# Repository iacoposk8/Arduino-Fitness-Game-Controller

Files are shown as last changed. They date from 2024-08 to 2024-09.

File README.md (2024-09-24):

Support me (https://buymeacoffee.com/iacoposk8)

# Arduino Fitness Game Controller
This project showcases an innovative Arduino-based controller that simulates the left analog stick of a gamepad, enabling control of in-game movements through physical activity. The controller is designed to be mounted on the user's back and integrates with exercise equipment like treadmills, stationary bikes, and ellipticals.

## Watch the demo video on YouTube
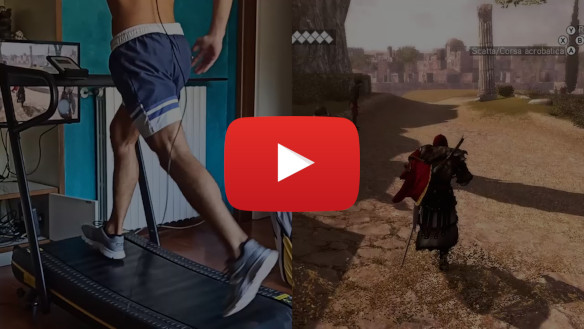
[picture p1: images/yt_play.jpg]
Demo video of the project (https://www.youtube.com/watch?v=4EYHZWyAiZI)


Demo gif of the project

## How to use

### Requirements

* Arduino nano
* GY-521 MPU-6050 accelerometer

### Electrical connections
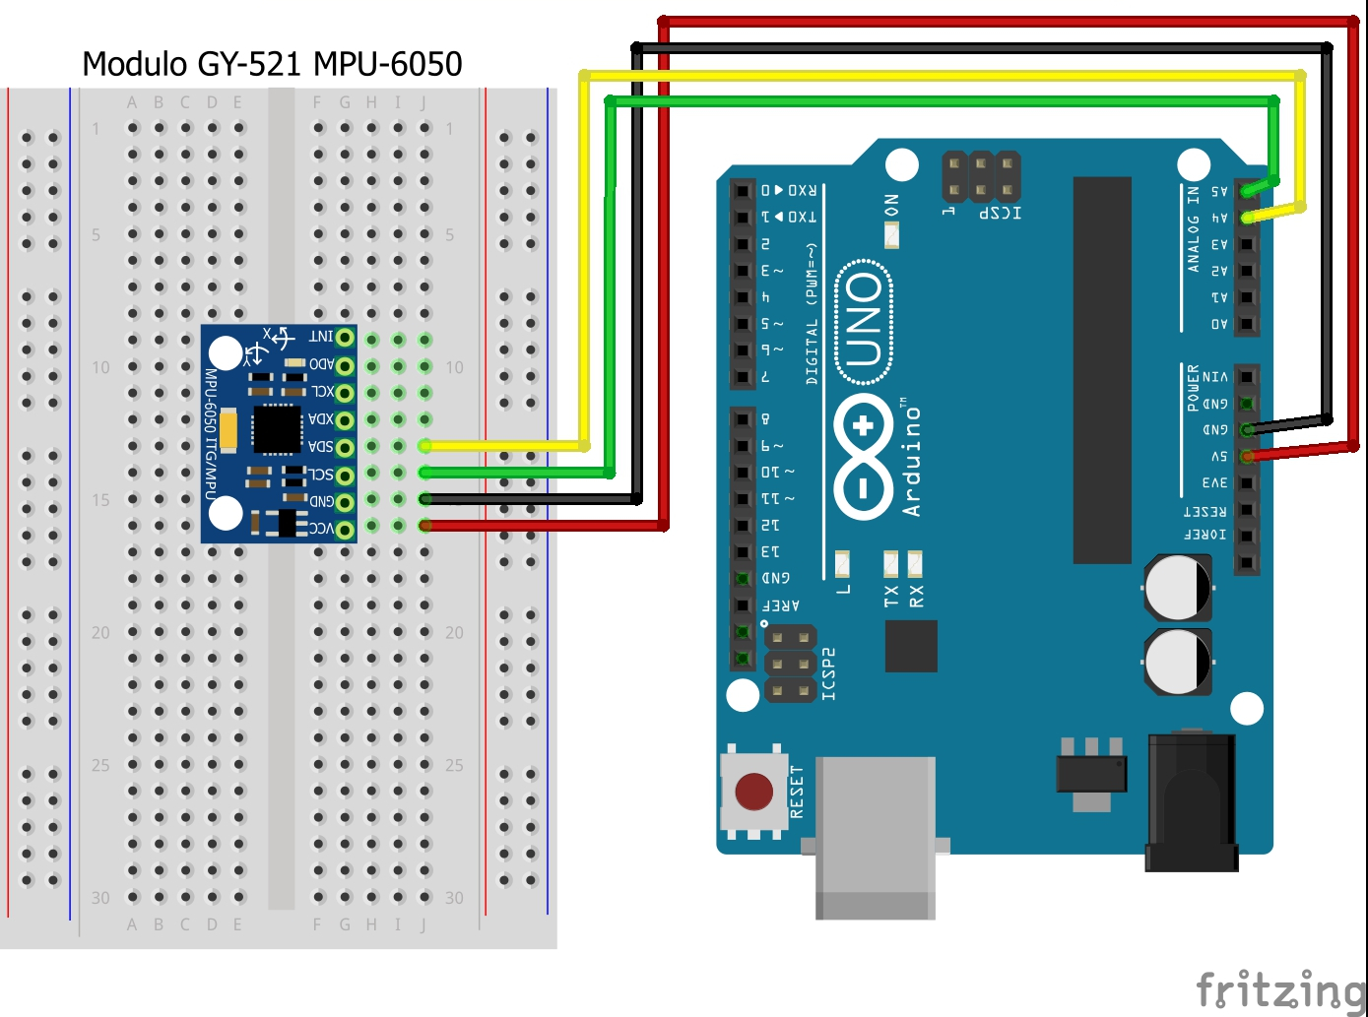
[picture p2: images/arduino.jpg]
Electrical connections


### Arduino code
Upload the code from the Accelerometer.ino file to your Arduino.
This code simply reads the accelerometer and sends the data to the serial port which will then be read by Controller.py

### Controller code
The Controller.py file will simulate the Xbox joystick and by reading the data from the arduino it will move the left analog stick.

I still need to create a requirements.txt file, but these commands probably install all the dependencies:
```
pip install pyserial
pip install numpy
pip install vgamepad
pip install matplotlib
```
### Configurations

In the first lines that follow `def __init__(self):` there are a few variables to configure to make the best use of the controller.

When we run we have vertical and horizontal oscillations that we could represent graphically as a sinusoid.
However, when we use a joystick, if we want to go in a direction, for example forward, we will not intermittently tap our analog stick, but we will tilt it forward while keeping it in that position.
So, if we took the raw data from the accelerometer while we are running, our character would continue to stop and start turning right and left at each of our steps.
So the code takes a sample of measurements and makes an average.
The larger the sample, the fewer errors there will be, but there will be a delay in executing the command.

The lower the value, the less movement of the shoulders to turn
```
self.x_range = 0.8
```

Threshold which, if exceeded, will start the curve
```
self.x_threshold = 0.4
```

The lower the value, the lower the speed at which we should run to make our character go at maximum speed
```
self.y_max_speed = 2.5
```

Speed with which we want, walk, run and run fast
Speed with which we want, walk, run and fast run
Currently the fast run is activated by pressing the "A" button on the Xbox controller. If you want to change it just change the lines:
gamepad.press_button(button=vg.XUSB_BUTTON.XUSB_GAMEPAD_A)
and
gamepad.release_button(button=vg.XUSB_BUTTON.XUSB_GAMEPAD_A)
With one of the commands that can be found here:
[https://pypi.org/project/vgamepad](https://pypi.org/project/vgamepad).

```
self.speed = {
	"walk": 0.06,
	"run": 0.3,
	"fast_run": 0.7
}
```

The higher the value, the less the left analog stick y-position flickers, but the return to zero position will be slower
```
self.n_sample_x = 2
self.n_sample_y = 10
```

If set to True the code will automatically find the right port, if it doesn't work, set it to False and during execution it will show you all the ports to choose from
```
automatic_choice_port = True
```

Optional ability to enable various types of debugging with graphs and logs
```
self.show_value = False
self.show_plot = False
self.x_plot = 200
self.debug = True
```
### 3D printing

In the Stl folder there are the files for 3d printing and the blender file for editing. This is the part of the project that needs to be fixed the most, in the future I will solder Arduino and the accelerometer so as not to have wires and I will be able to create a closed case. But for those who want to try this project these models are enough.
You will find two folders, one with the models with clips and one without clips.

| With clip | Without clip |
|--|--|
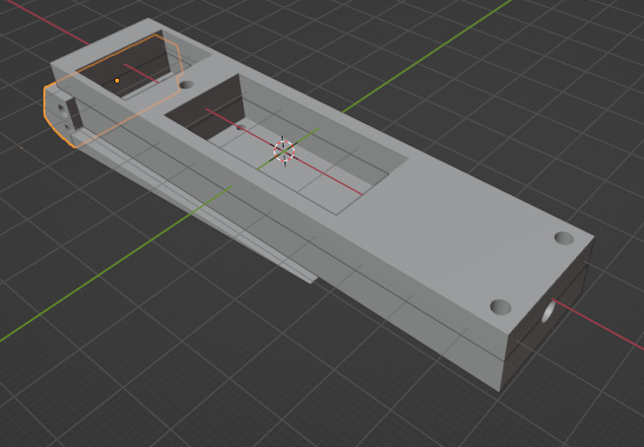
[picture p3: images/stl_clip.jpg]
Support with clip
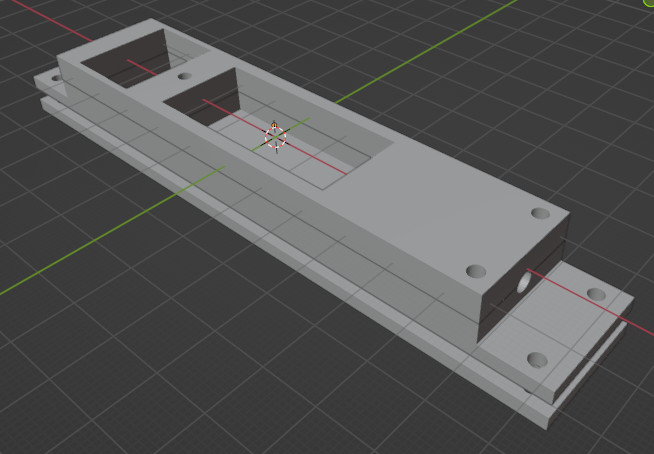
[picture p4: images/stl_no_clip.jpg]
Support without clip
|  |  |

The model without clips can be mounted on [this back support by Dreamfit](https://www.amazon.it/gp/product/B07QPVP33F).
The model with clips goes on all shirts but you will notice that it will swing a lot while running, so you will have to find a way to fix the cable at the bottom of the shirt or in the middle.

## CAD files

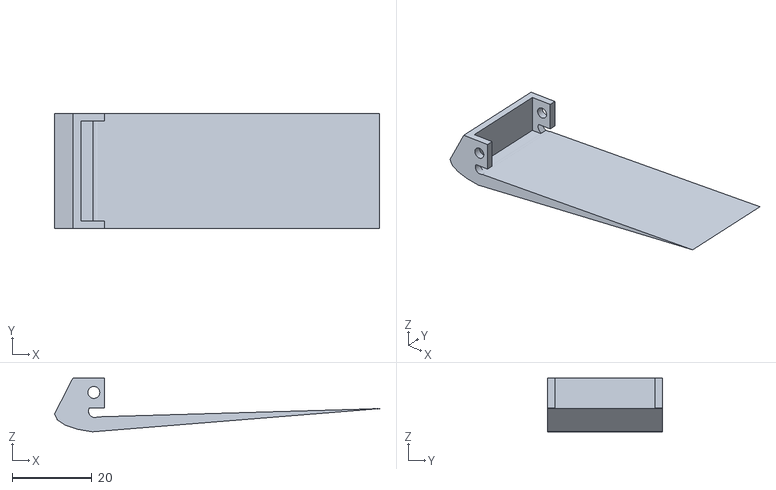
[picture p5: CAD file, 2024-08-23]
Stl/Clip/clip.stl
81.6 x 29.0 x 13.6

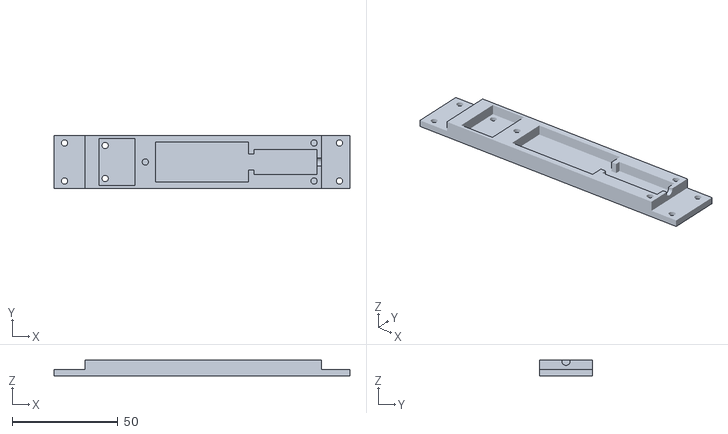
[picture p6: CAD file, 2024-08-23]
Stl/Without clip/bottom.stl
140.0 x 25.0 x 7.50

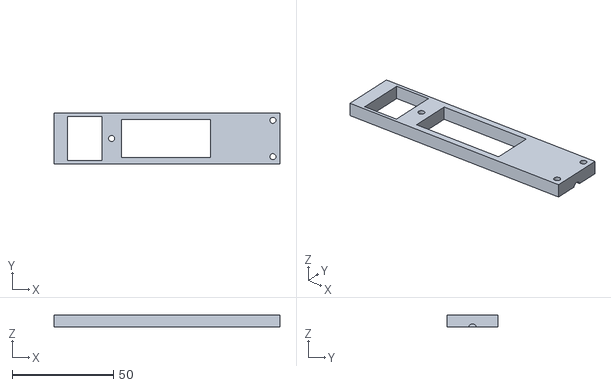
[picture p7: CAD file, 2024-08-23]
Stl/Clip/top.stl
111.8 x 25.0 x 6.00

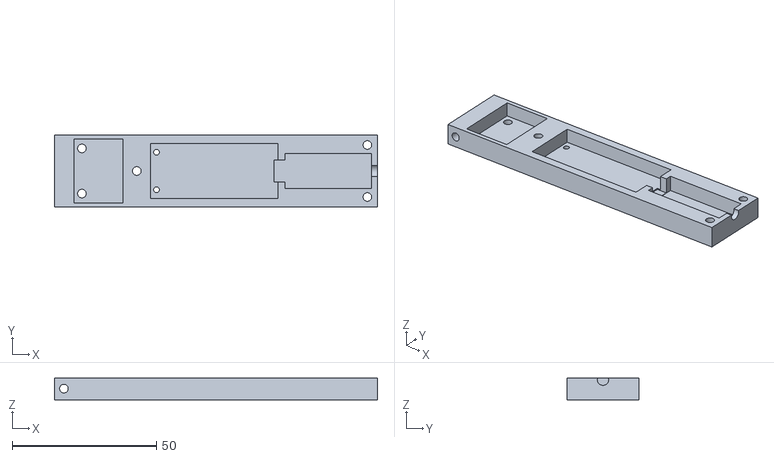
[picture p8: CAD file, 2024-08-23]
Stl/Clip/bottom.stl
111.8 x 25.0 x 7.50

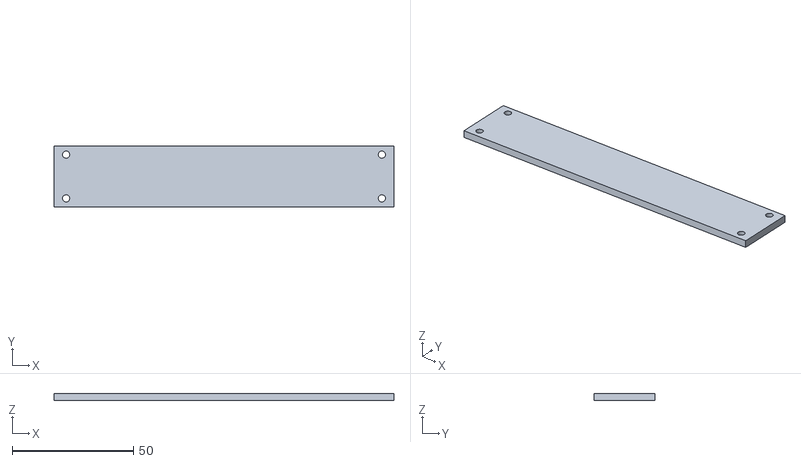
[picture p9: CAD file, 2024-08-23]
Stl/Without clip/closing.stl
140.0 x 25.0 x 3.00

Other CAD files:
Stl/Clip/with clip.blend
Stl/Without clip/without clip.blend

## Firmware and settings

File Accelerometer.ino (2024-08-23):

#include <MPU6050_tockn.h>
#include <Wire.h>

MPU6050 mpu6050(Wire);

long timer = 0;

void setup() {
  Serial.begin(38400);
  Serial.println("Wire");
  Wire.begin();
  Serial.println("mpu6050");
  mpu6050.begin();
  Serial.println("calcGyroOffsets");
  mpu6050.calcGyroOffsets(true);
  Serial.println("Setup Finish");
}

void loop() {
  mpu6050.update();

  //if(millis() - timer > 1000){

    String buf;
    buf += F("{");

    buf += F("\"temp\": ");
    buf += String(mpu6050.getTemp());
    buf += F(",");

    buf += F("\"accX\": ");
    buf += String(mpu6050.getAccX());
    buf += F(",");

    buf += F("\"accY\": ");
    buf += String(mpu6050.getAccY());
    buf += F(",");

    buf += F("\"accZ\": ");
    buf += String(mpu6050.getAccZ());
    buf += F(",");

    buf += F("\"gyroX\": ");
    buf += String(mpu6050.getGyroX());
    buf += F(",");

    buf += F("\"gyroY\": ");
    buf += String(mpu6050.getGyroY());
    buf += F(",");

    buf += F("\"gyroZ\": ");
    buf += String(mpu6050.getGyroZ());
    buf += F(",");

    buf += F("\"accAngleX\": ");
    buf += String(mpu6050.getAccAngleX());
    buf += F(",");

    buf += F("\"accAngleY\": ");
    buf += String(mpu6050.getAccAngleY());
    buf += F(",");

    buf += F("\"gyroAngleX\": ");
    buf += String(mpu6050.getGyroAngleX());
    buf += F(",");

    buf += F("\"gyroAngleY\": ");
    buf += String(mpu6050.getGyroAngleY());
    buf += F(",");

    buf += F("\"gyroAngleZ\": ");
    buf += String(mpu6050.getGyroAngleZ());
    buf += F(",");

    buf += F("\"angleX\": ");
    buf += String(mpu6050.getAngleX());
    buf += F(",");

    buf += F("\"angleY\": ");
    buf += String(mpu6050.getAngleY());
    buf += F(",");

    buf += F("\"angleZ\": ");
    buf += String(mpu6050.getAngleZ());
    //buf += F(",");

    buf += F("}");


    Serial.print(buf);
    Serial.println("");

    //timer = millis();
    
    /*Serial.println("=======================================================");
    Serial.print("temp : ");Serial.println(mpu6050.getTemp());
    Serial.print("accX : ");Serial.print(mpu6050.getAccX());
    Serial.print("\taccY : ");Serial.print(mpu6050.getAccY());
    Serial.print("\taccZ : ");Serial.println(mpu6050.getAccZ());
  
    Serial.print("gyroX : ");Serial.print(mpu6050.getGyroX());
    Serial.print("\tgyroY : ");Serial.print(mpu6050.getGyroY());
    Serial.print("\tgyroZ : ");Serial.println(mpu6050.getGyroZ());
  
    Serial.print("accAngleX : ");Serial.print(mpu6050.getAccAngleX());
    Serial.print("\taccAngleY : ");Serial.println(mpu6050.getAccAngleY());
  
    Serial.print("gyroAngleX : ");Serial.print(mpu6050.getGyroAngleX());
    Serial.print("\tgyroAngleY : ");Serial.print(mpu6050.getGyroAngleY());
    Serial.print("\tgyroAngleZ : ");Serial.println(mpu6050.getGyroAngleZ());
    
    Serial.print("angleX : ");Serial.print(mpu6050.getAngleX());
    Serial.print("\tangleY : ");Serial.print(mpu6050.getAngleY());
    Serial.print("\tangleZ : ");Serial.println(mpu6050.getAngleZ());
    Serial.println("=======================================================\n");
    timer = millis();*/
    
  //}

}

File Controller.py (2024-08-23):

#python -m pip install pyserial
import serial
import time
import json
import os
import traceback
import serial.tools.list_ports
import numpy as np
import threading
import matplotlib.pyplot as plt
import matplotlib.animation as animation

import vgamepad as vg
gamepad = vg.VX360Gamepad()

class Accelerometer:
	def Action(self, line):
		self.xpos = float((sum(self.accy_sample) / len(self.accy_sample)) / self.x_range)
		
		if self.xpos > 1:
			self.xpos = 1.0
		if self.xpos < -1:
			self.xpos = -1.0
		if self.xpos < self.x_threshold and self.xpos > (self.x_threshold * -1):
			self.xpos = 0
		'''else:
			print(self.xpos)'''

		self.ypos = float((max(self.acc_sample) - 1) / self.y_max_speed)
		if self.ypos > 1:
			self.ypos = 1.0
		if self.ypos < -0:
			self.ypos = 0.0
		
		print(self.ypos)

		if self.show_plot:
			self.y["custom"].append(self.xpos)
			self.y["custom"] = self.y["custom"][(self.x_plot * -1):]
			self.lines["custom"].set_ydata(self.y["custom"])

	def move_joystick(self):
		while True:
			try:
				joystick_ypos = 0
				if self.ypos >= self.speed["walk"]:
					joystick_ypos = 1

				#print(self.xpos,self.ypos)
				gamepad.left_joystick_float(x_value_float=self.xpos, y_value_float=joystick_ypos)

				if self.ypos >= self.speed["run"]:
					gamepad.right_trigger_float(self.ypos)
				else:
					gamepad.right_trigger_float(0)

				if self.ypos >= self.speed["fast_run"]:
					gamepad.press_button(button=vg.XUSB_BUTTON.XUSB_GAMEPAD_A)
				else:
					gamepad.release_button(button=vg.XUSB_BUTTON.XUSB_GAMEPAD_A)
				
				gamepad.update()

				#gamepad.reset()
				#gamepad.update()
				
				if self.xpos == 0 and self.ypos == 0:
					#time.sleep(0.1)
					gamepad.reset()
					gamepad.update()
			except AttributeError:
				continue

			time.sleep(0.1)

	def __init__(self):
		#The lower the value, the less movement of the shoulders to turn
		self.x_range = 0.8 

		#threshold which, if exceeded, will start the curve
		self.x_threshold = 0.4
		
		#the lower the value, the lower the speed at which we should run to make our character go at maximum speed
		self.y_max_speed = 2.5

		#Speed with which we want, walk, run and run fast
		#Speed with which we want, walk, run and fast run
		#Currently the fast run is activated by pressing the "A" button on the Xbox controller. If you want to change it just change the lines:
		#gamepad.press_button(button=vg.XUSB_BUTTON.XUSB_GAMEPAD_A)
		#and
		#gamepad.release_button(button=vg.XUSB_BUTTON.XUSB_GAMEPAD_A)
		#With one of the commands that can be found here
		#https://pypi.org/project/vgamepad/
		self.speed = {
			"walk": 0.06,
			"run": 0.3,
			"fast_run": 0.7
		}
		
		#the higher the value, the less the left analog stick y-position flickers, but the return to zero position will be slower
		self.n_sample_x = 2
		self.n_sample_y = 10

		#If set to True the code will automatically find the right port, if it doesn't work, set it to False and during execution it will show you all the ports to choose from
		automatic_choice_port = True

		#optional ability to enable various types of debugging with graphs and logs
		self.show_value = False
		self.show_plot = False
		self.x_plot = 200
		self.debug = True
		
		self.baudrate = 38400 #19200 31250 38400 57600 74880 115200

		#temp acc gyro accAngle gyroAngle angle
		self.data_type = "acc"

		self.acc_sample = []
		self.accy_sample = []
		
		ports = serial.tools.list_ports.comports()
		probable_port = 1
		if not automatic_choice_port:
			print("Ports:")
		for i in range(len(ports)):
			if "CH340" in ports[i]:
				probable_port = i
			if not automatic_choice_port:
				print("["+str(i)+"]",ports[i])

		if automatic_choice_port:
			port = probable_port
		else:
			port = input("Select the port: ")
		self.arduino = serial.Serial(port=str(ports[int(port)]).split("-")[0].strip(), baudrate=self.baudrate, timeout=0.1) #'/dev/ttyUSB0'

		self.maxVal = {
			"acc": 4,
			"gyro": 500,
			"accAngle": 150,
			"gyroAngle": 500,
			"angle": 500
		}

		self.clear = lambda: os.system("cls")

		#self.start()
		x = threading.Thread(target=self.read_sensor, args=())
		x.start()

		x = threading.Thread(target=self.move_joystick, args=())
		x.start()

		if self.show_plot:
			self.y = {"X": [0] * self.x_plot, "Y": [0] * self.x_plot, "Z": [0] * self.x_plot, "custom": [0] * self.x_plot}
			self.y["X"][0] = self.maxVal[self.data_type]
			self.y["X"][1] = self.maxVal[self.data_type] * -1

			fig = plt.figure()
			ax = fig.add_subplot(1, 1, 1)

			self.lines = {}
			self.lines["X"] = ax.plot(self.y["X"], animated=True)[0]
			self.lines["Y"] = ax.plot(self.y["Y"], animated=True)[0]
			self.lines["Z"] = ax.plot(self.y["Z"], animated=True)[0]
			self.lines["custom"] = ax.plot(self.y["custom"], animated=True)[0]

			ani = animation.FuncAnimation(fig, self.animate, interval=100, blit=True)
			plt.show()

	def animate(self, i):
		return [self.lines["X"], self.lines["Y"], self.lines["Z"], self.lines["custom"]]

	def read_sensor(self):
		start_time = 0
		read_start = False
		while True:
			try:
				line = self.arduino.readline()
				if not line:
					continue

				line = line.decode("utf-8").rstrip()
				if line == "":
					continue

				line = json.loads(line)

				if self.show_value:
					self.clear()

				#for cord in ["X", "Y", "Z"]:
				for cord in ["Y"]:
					par = self.data_type + cord
					if par in line:
						if self.show_value:
							print(par+": "+str(line[par]))

						if self.show_plot:
							self.y[cord].append(line[self.data_type + cord])
							self.y[cord] = self.y[cord][(self.x_plot * -1):]
							self.lines[cord].set_ydata(self.y[cord])

				accel_mag = np.sqrt((line["accX"] ** 2 + line["accY"] ** 2 + line["accZ"] ** 2))
				self.acc_sample.append(accel_mag)
				self.acc_sample = self.acc_sample[self.n_sample_y * -1:]

				self.accy_sample.append(line["accY"])
				self.accy_sample = self.accy_sample[self.n_sample_x * -1:]

				read_start = True

				self.Action(line)
				#time.sleep(1 / 115200)
				time.sleep(1 / self.baudrate)
			except json.decoder.JSONDecodeError:
				#print("ERROR")
				if read_start == False or self.debug:
					print(line)
			except UnicodeDecodeError:
				pass
			except KeyboardInterrupt:
				break
			except:
				traceback.print_exc()

Accelerometer()
